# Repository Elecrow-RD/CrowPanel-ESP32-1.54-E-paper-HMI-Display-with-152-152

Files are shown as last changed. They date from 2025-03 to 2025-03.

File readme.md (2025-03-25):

### 1, Product picture

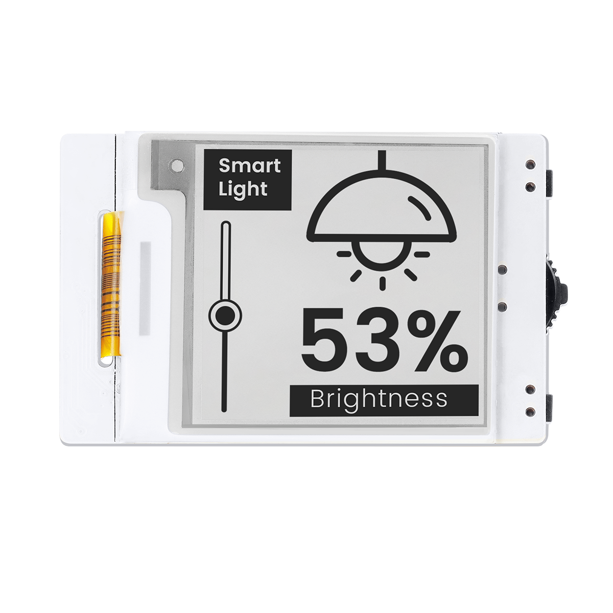
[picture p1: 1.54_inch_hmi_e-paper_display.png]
1.54_inch_hmi_e-paper_display


### 2, Product version number

| | Hardware | Software | Remark |
| ---- | --- | --- | --- |
| 1 | V1.0 | V1.0 | latest |

### 3, product information

#### Display Module Specifications

- Size: 1.54 inch
- MCU: ESP32-S3, up to 240 MHz
- Flash: 8 MB
- PSRAM: 8 MB
- Material: Active Matrix Electrophoretic Display (AM EPD)
- Driver Chip: SSD1680
- Resolution: 128(H)*296(V) Pixel
- Pixel pitch: 0.227*0.226
- Viewing Angle: Full Viewing Angle
- Communication interface: 3-/4-wire SPI
- Interface: UART0 x1, BAT x1
- Button: Dial Switch x1, Menu Button x1, Back Button x1, REST Button x1, BOOT Button x1
- Development Environment: Arduino IDE、ESP IDF、MicroPython
- Display Color: Black and white
- Refresh Mode: Partial refresh (saves more power)
- Display Operation Voltage: 2.2~3.7V
- Acrylic Case: White Acrylic Case
- Operation Temperature: -0~50℃
- Storage Temperature: -25~70℃
- Active Area: 37.18(H)\*48.32(L) (H*L)

### 4, Use the driver module

| Name | dependency library |
| --- | --- |
| SSD1680 | EPD<br />version=1.0.0 |

### 5,Quick Start

##### Arduino IDE starts

1.Download the library files used by this product to the 'libraries' folder.

C:\Users\Documents\Arduino\libraries\



2.Open the Arduino IDE

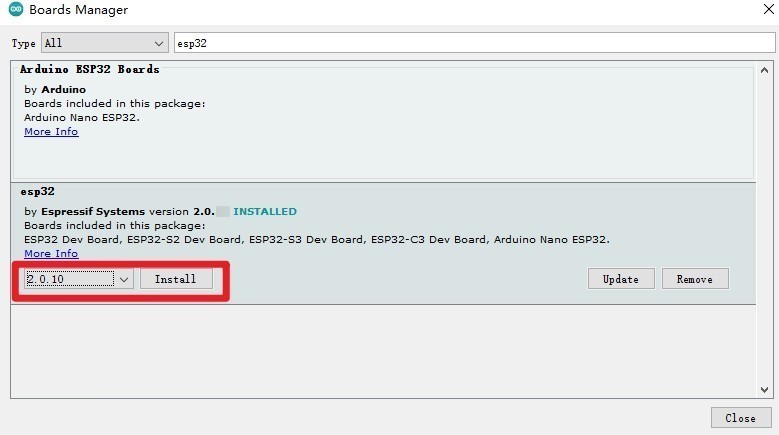
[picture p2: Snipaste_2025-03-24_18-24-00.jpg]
Snipaste_2025-03-24_18-24-00


3.Open the code configuration environment and burn it

setting

### 6,Folder structure.

|--3D file： Contains 3D model files (.stp) for the hardware. These files can be used for visualization, enclosure design, or integration into CAD software.

|--Datasheet: Includes datasheets for components used in the project, providing detailed specifications, electrical characteristics, and pin configurations.

|--Eagle_SCH&PCB: Contains **Eagle CAD** schematic (`.sch`) and PCB layout (`.brd`) files. These are used for circuit design and PCB manufacturing.

|--example: Provides example code and projects to demonstrate how to use the hardware and libraries. These examples help users get started quickly.

|--factory_firmware: Stores pre-compiled factory firmware that can be directly flashed onto the device. This ensures the device runs the default functionality.

|--factory_sourcecode: Contains the source code for the factory firmware, allowing users to modify and rebuild the firmware as needed.

### 7,Pin definition

#define SCK 12

#define MOSI 11

#define RES 10

#define DC 13

#define CS 14

#define BUSY 9

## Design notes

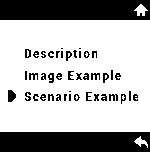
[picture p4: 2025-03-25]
factory_soucecode/1.54_tow/pic/ui_1-54_BW/UI_1-54_BW_拨轮页面-03.bmp

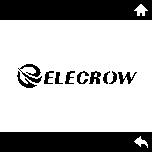
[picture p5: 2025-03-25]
factory_soucecode/1.54_tow/pic/NEW_UI_1-54_BW_/NEW_UI_1-54_BW_img-01.bmp

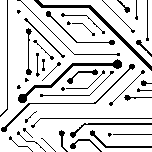
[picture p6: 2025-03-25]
factory_soucecode/1.54_tow/pic/ui_1-54_BW/UI_1-54_BW_img-07.bmp

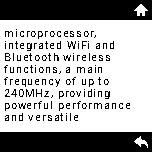
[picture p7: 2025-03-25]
factory_soucecode/1.54_tow/pic/NEW_UI_1-54_BW_202408_02/NEW_UI_1-54_BW_202408_02/NEW_UI_1-54_BW_Product-Description-02.bmp

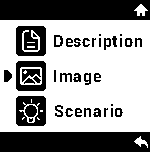
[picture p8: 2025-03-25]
factory_soucecode/1.54_tow/pic/NEW_UI_1-54_BW_/NEW_UI_1-54_BW_拨轮页面-02.bmp

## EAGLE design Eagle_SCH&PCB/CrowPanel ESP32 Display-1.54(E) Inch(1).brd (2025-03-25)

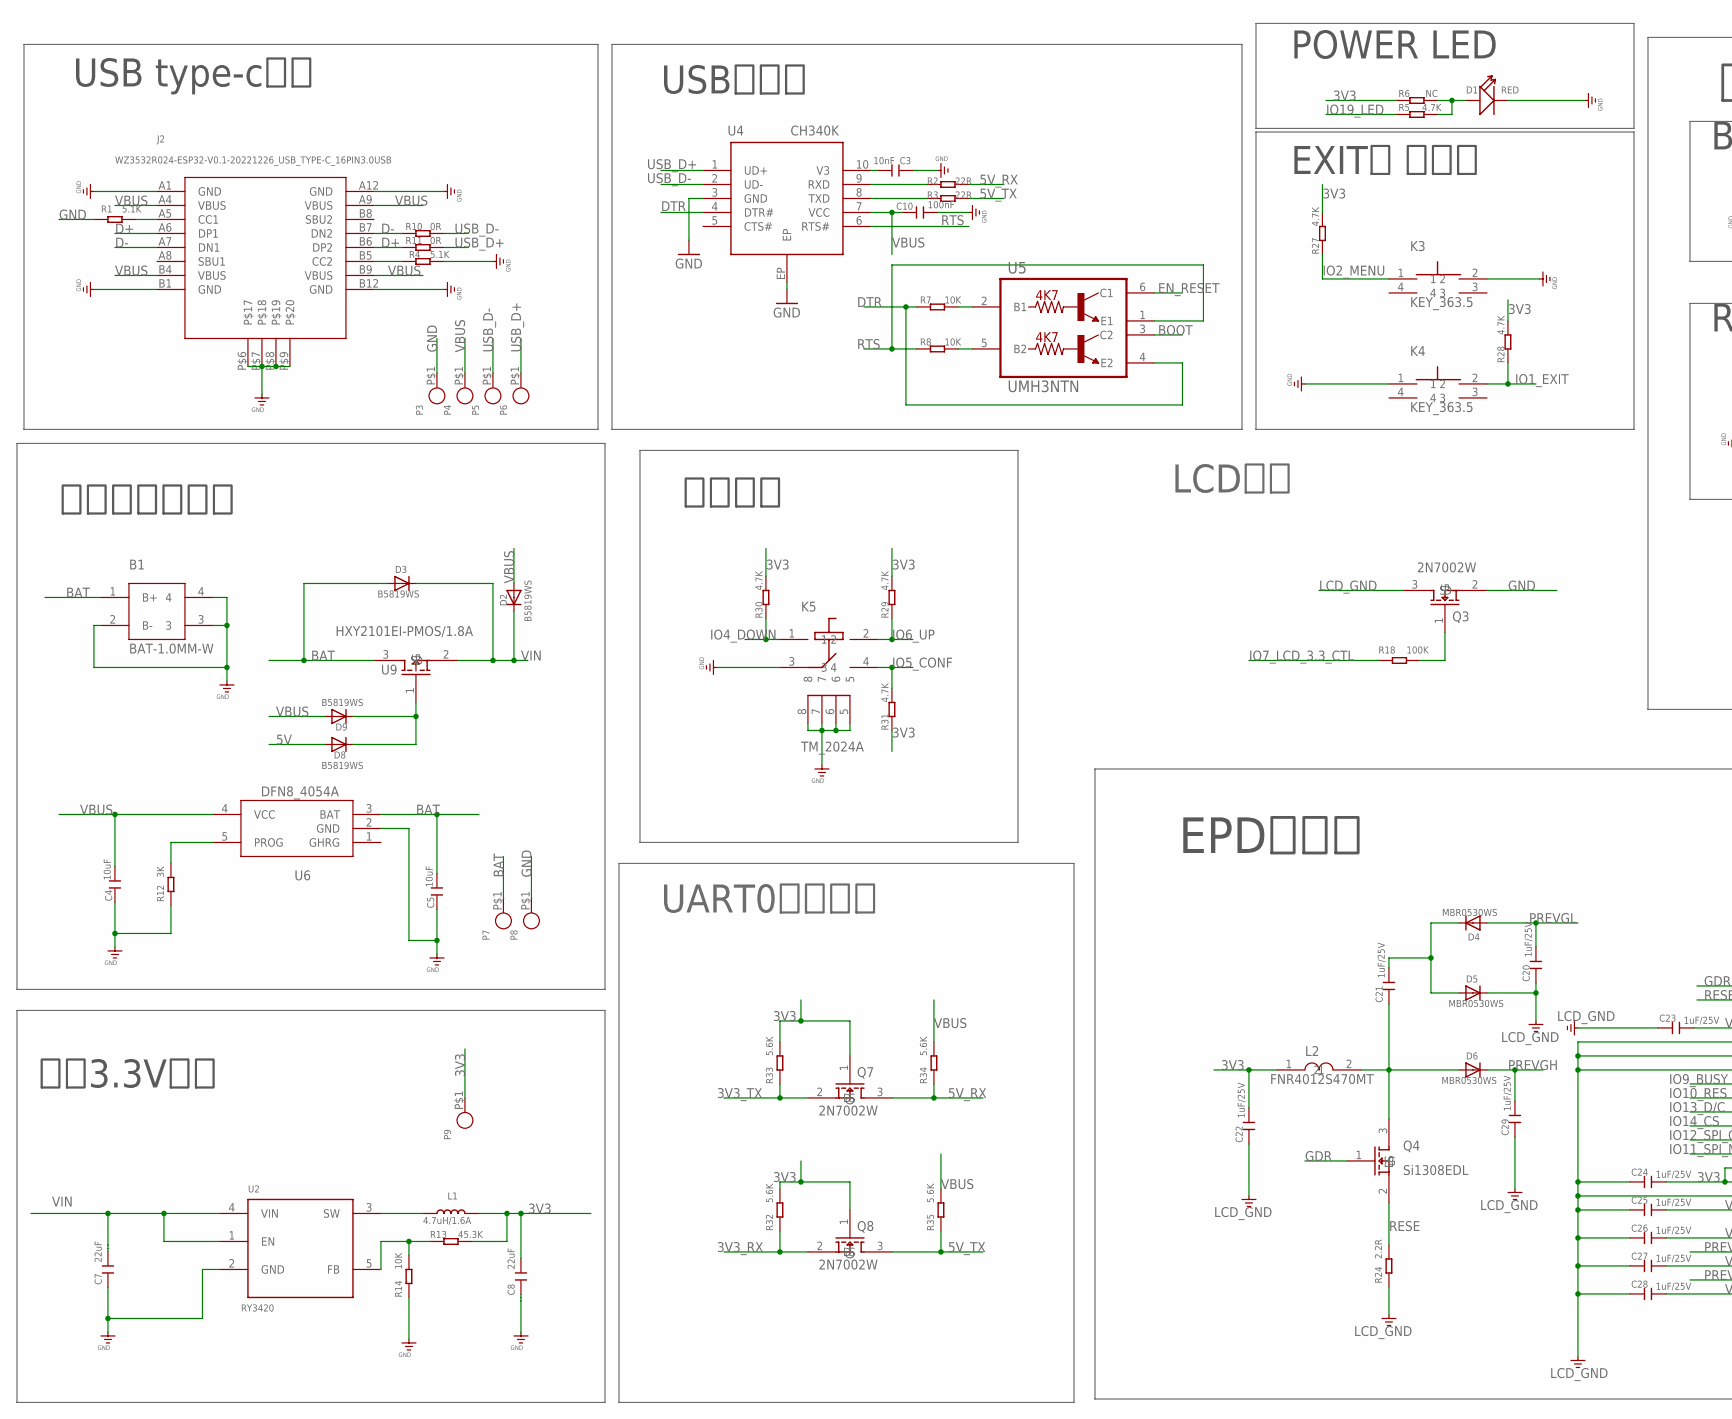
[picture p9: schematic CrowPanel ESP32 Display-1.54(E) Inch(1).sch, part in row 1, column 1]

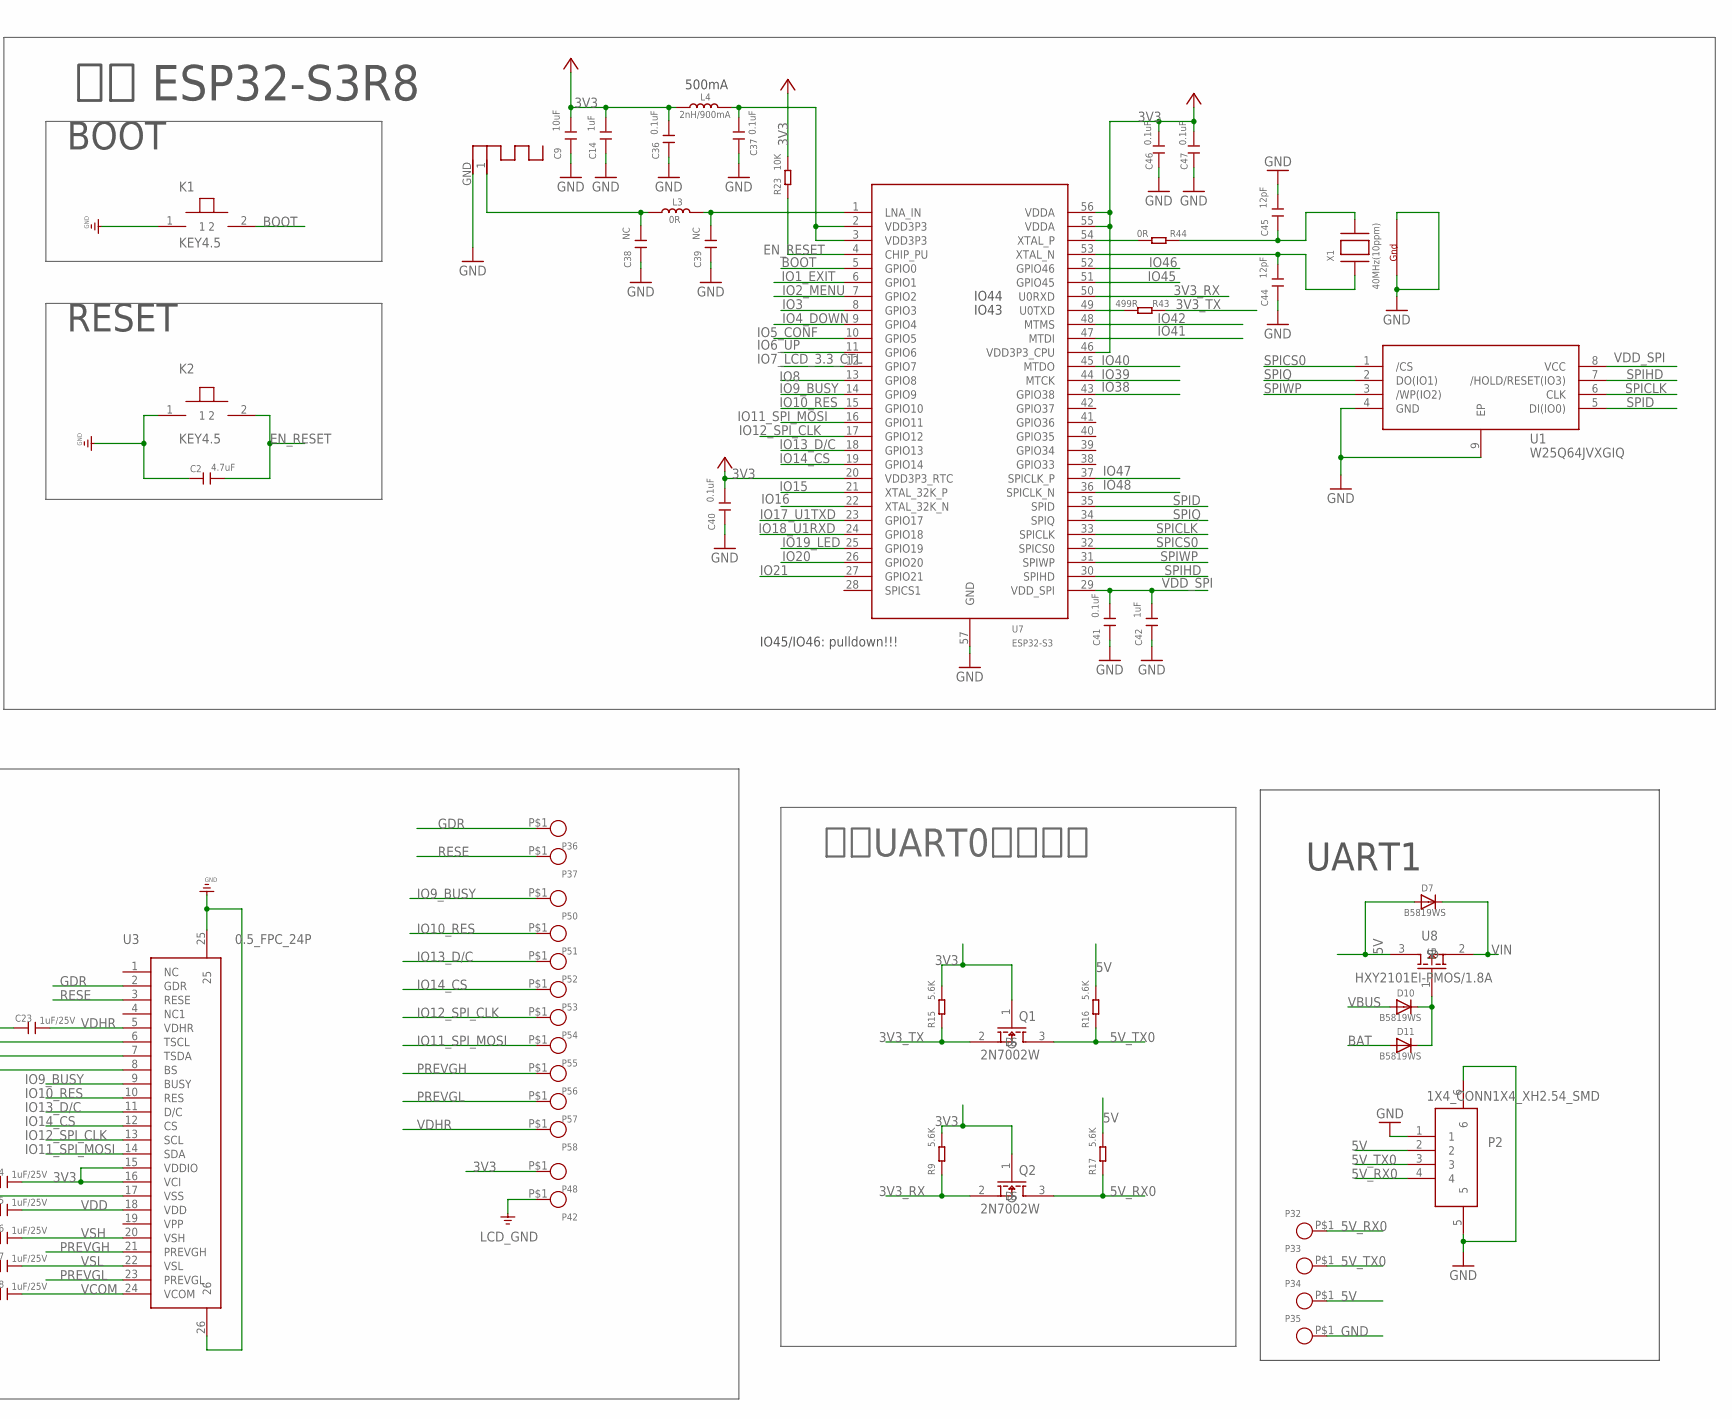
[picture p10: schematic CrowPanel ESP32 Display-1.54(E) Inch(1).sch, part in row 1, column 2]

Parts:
ANT1: ADAFRUIT_ANTENNA; ADAFRUIT_RN-ANT
B1: BAT-1.0MM-W; SH1.0MM-W
C2: 4.7uF; 0402
C3: 10nF; 0402
C4, C5, C9: 10uF; 0402
C7, C8: 22uF; 0603
C10: 100nF; 0402
C14, C42: 1uF; 0402
C20, C21, C22, C23, C24, C25, C26, C27, C28, C29: 1uF/25V; 0402
C36, C37, C40, C41, C46, C47: 0.1uF; 0402
C38, C39: NC; 0402
C44, C45: 12pF; 0402
D1: RED; A_XBJ_DISCRETE_LED-0603
D2, D3, D7, D8, D9, D10, D11: B5819WS; DISCRETE_SOD323
D4, D5, D6: MBR0530WS; DISCRETE_SOD323
J2: WZ3532R024-ESP32-V0.1-20221226_USB_TYPE-C_16PIN3.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; WZ3532R024-ESP32-V0.1-20221226_KEVIN_3.0TYPEC-SMD
K1, K2: KEY4.5; KEY-4.5
K3, K4: KEY_363.5; KEY_3*6*3.5
K5: TM_2024A
L1: 4.7uH/1.6A; A9G_DISCRETE_L0805
L2: FNR4012S470MT
L3: 0R; L0402
L4: 2nH/900mA; L0402
P2: 1X4_CONN1X4_XH2.54_SMD; CONN-SMD-4P-P2.54
P3, P4, P5, P6, P7, P8, P9, P32, P33, P34, P35, P36, P37, P42, P48, P50, P51, P52, P53, P54, P55, P56, P57, P58: CROWPI_POW_PADPAD-1.0MM; CROWPI_POW_PAD-1.0MM
Q1, Q2, Q3, Q7, Q8: 2N7002W; SOT-323_W
Q4: Si1308EDL; SOT-323_W
R1, R4: 5.1K; 0402
R2, R3: 22R; 0402
R5, R27, R28, R29, R30, R31: 4.7K; 0402
R6: NC; 0402
R7, R8, R14, R23: 10K; 0402
R9, R15, R16, R17, R32, R33, R34, R35: 5.6K; 0402
R10, R11, R44: 0R; 0402
R12: 3K; 0402
R13: 45.3K; 0402
R18: 100K; 0402
R24: 2.2R; 0402
R43: 499R; 0402
U1: W25Q64JVXGIQ; XSON-EP(4×4)
U2: RY3420; CROWBOT_-V1.0-20220525_A_XBJ_SOT23-5
U3: 0.5_FPC_24P
U4: CH340K; ESOP-10-EP-150MIL
U5: UMH3NTN; SOP65P210X100-6N
U6: DFN8_4054A; DFN8_SOP23-5
U7: ESP32-S3; QFN56-7*7MM
U8, U9: HXY2101EI-PMOS/1.8A; SOT-323_W
X1: 40MHz(10ppm); ADAFRUIT_NX3225

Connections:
3V3: C8.2, C9.2, C14.2, C22.1, C24.1, C36.2, C40.2, C46.2, C47.2, L1.2, L2.1, L4.1, P9.P$1, P48.P$1, Q1.1 (G), Q2.1 (G), Q7.1 (G), Q8.1 (G), R6.2, R9.2, R13.2, R15.2, R23.2, R27.2, R28.2, R29.2, R30.2, R31.1, R32.2, R33.2, U3.15 (VDDIO), U3.16 (VCI), U7.20 (VDD3P3_RTC), U7.46 (VDD3P3_CPU), U7.55 (VDDA), U7.56 (VDDA)
3V3_RX: Q2.2 (S), Q8.2 (S), R9.1, R32.1, U7.50 (U0RXD)
3V3_TX: Q1.2 (S), Q7.2 (S), R15.1, R33.1, R43.1
5V: D7.+ (A), D8.+ (A), P2.2, P34.P$1, R16.2, R17.2, U8.3 (D)
5V_RX: Q7.3 (D), R2.2, R34.1
5V_RX0: P2.4, P32.P$1, Q2.3 (D), R17.1
5V_TX: Q8.3 (D), R3.2, R35.1
5V_TX0: P2.3, P33.P$1, Q1.3 (D), R16.1
BAT: B1.1 (B+), C5.2, D3.+ (A), D11.+ (A), P7.P$1, U6.3 (BAT), U9.3 (D)
BOOT: K1.2, U5.3 (C2), U7.5 (GPIO0)
D+: J2.A6 (DP1), J2.B6 (DP2), R11.1
D-: J2.A7 (DN1), J2.B7 (DN2), R10.1
DTR: R7.1, U4.4 (DTR#), U5.4 (E2)
EN_RESET: C2.2, K2.2, R23.1, U5.6 (C1), U7.4 (CHIP_PU)
GDR: P36.P$1, Q4.1 (G), U3.2 (GDR)
GND: ANT1.GND, B1.2 (B-), B1.3, B1.4, C2.1, C3.1, C4.1, C5.1, C7.1, C8.1, C9.1, C10.2, C14.1, C36.1, C37.1, C38.1, C39.1, C40.1, C41.1, C42.1, C44.1, C45.2, C46.1, C47.1, D1.-, J2.A1 (GND), J2.A12 (GND), J2.B1 (GND), J2.B12 (GND), J2.P$6, J2.P$7, J2.P$8, J2.P$9, K1.1, K2.1, K3.2, K4.1, K5.3, K5.5, K5.6, K5.7, K5.8, P2.1, P2.5, P2.6, P3.P$1, P8.P$1, P35.P$1, Q3.2 (S), R1.1, R4.2, R12.1, R14.1, U1.4 (GND), U1.9 (EP), U2.2 (GND), U3.25, U3.26, U4.3 (GND), U4.EP, U6.2 (GND), U7.57 (GND), X1.2 (G2), X1.4 (G1)
IO1_EXIT: K4.2, R28.1, U7.6 (GPIO1)
IO2_MENU: K3.1, R27.1, U7.7 (GPIO2)
IO3: U7.8 (GPIO3)
IO4_DOWN: K5.1, R30.1, U7.9 (GPIO4)
IO5_CONF: K5.4, R31.2, U7.10 (GPIO5)
IO6_UP: K5.2, R29.1, U7.11 (GPIO6)
IO7_LCD_3.3_CTL: R18.1, U7.12 (GPIO7)
IO8: U7.13 (GPIO8)
IO9_BUSY: P50.P$1, U3.9 (BUSY), U7.14 (GPIO9)
IO10_RES: P51.P$1, U3.10 (RES), U7.15 (GPIO10)
IO11_SPI_MOSI: P55.P$1, U3.14 (SDA), U7.16 (GPIO11)
IO12_SPI_CLK: P54.P$1, U3.13 (SCL), U7.17 (GPIO12)
IO13_D/C: P52.P$1, U3.11 (D/C), U7.18 (GPIO13)
IO14_CS: P53.P$1, U3.12 (CS), U7.19 (GPIO14)
IO15: U7.21 (XTAL_32K_P)
IO16: U7.22 (XTAL_32K_N)
IO17_U1TXD: U7.23 (GPIO17)
IO18_U1RXD: U7.24 (GPIO18)
IO19_LED: R5.2, U7.25 (GPIO19)
IO20: U7.26 (GPIO20)
IO21: U7.27 (GPIO21)
IO38: U7.43 (GPIO38)
IO39: U7.44 (MTCK)
IO40: U7.45 (MTDO)
IO41: U7.47 (MTDI)
IO42: U7.48 (MTMS)
IO45: U7.51 (GPIO45)
IO46: U7.52 (GPIO46)
IO47: U7.37 (SPICLK_P)
IO48: U7.36 (SPICLK_N)
LCD_GND: C20.2, C22.2, C23.2, C24.2, C25.2, C26.2, C27.2, C28.2, C29.2, D5.- (C), P42.P$1, Q3.3 (D), R24.1, U3.6 (TSCL), U3.7 (TSDA), U3.8 (BS), U3.17 (VSS)
unnamed: R7.2, U5.2 (B1)
unnamed: D10.- (C), D11.- (C), U8.1 (G)
unnamed: R8.2, U5.5 (B2)
unnamed: J2.A5 (CC1), R1.2
unnamed: D8.- (C), D9.- (C), U9.1 (G)
unnamed: Q3.1 (G), R18.2
unnamed: R3.1, U4.8 (TXD)
unnamed: R13.1, R14.2, U2.5 (FB)
unnamed: C3.2, U4.10 (V3)
unnamed: L1.1, U2.3 (SW)
unnamed: J2.B5 (CC2), R4.1
unnamed: R12.2, U6.5 (PROG)
unnamed: D1.+, R5.1, R6.1
unnamed: ANT1.1 (FEED), C38.2, L3.1
unnamed: C39.2, L3.2, U7.1 (LNA_IN)
unnamed: C37.2, L4.2, U7.2 (VDD3P3), U7.3 (VDD3P3)
unnamed: R2.1, U4.9 (RXD)
unnamed: R44.2, U7.54 (XTAL_P)
unnamed: C21.1, D4.- (C), D5.+ (A)
unnamed: C21.2, D6.+ (A), L2.2, Q4.3 (D)
unnamed: R43.2, U7.49 (U0TXD)
unnamed: C44.2, U7.53 (XTAL_N), X1.1 (X1)
unnamed: C45.1, R44.1, X1.3 (X2)
PREVGH: C29.1, D6.- (C), P56.P$1, U3.21 (PREVGH)
PREVGL: C20.1, D4.+ (A), P57.P$1, U3.23 (PREVGL)
RESE: P37.P$1, Q4.2 (S), R24.2, U3.3 (RESE)
RTS: R8.1, U4.6 (RTS#), U5.1 (E1)
SPICLK: U1.6 (CLK), U7.33 (SPICLK)
SPICS0: U1.1 (/CS), U7.32 (SPICS0)
SPID: U1.5 (DI(IO0)), U7.35 (SPID)
SPIHD: U1.7 (/HOLD/RESET(IO3)), U7.30 (SPIHD)
SPIQ: U1.2 (DO(IO1)), U7.34 (SPIQ)
SPIWP: U1.3 (/WP(IO2)), U7.31 (SPIWP)
USB_D+: P6.P$1, R11.2, U4.1 (UD+)
USB_D-: P5.P$1, R10.2, U4.2 (UD-)
VBUS: C4.2, C10.1, D2.+ (A), D9.+ (A), D10.+ (A), J2.A4 (VBUS), J2.A9 (VBUS), J2.B4 (VBUS), J2.B9 (VBUS), P4.P$1, R34.2, R35.2, U4.7 (VCC), U6.4 (VCC)
VCOM: C28.1, U3.24 (VCOM)
VDD: C25.1, U3.18 (VDD)
VDD_SPI: C41.2, C42.2, U1.8 (VCC), U7.29 (VDD_SPI)
VDHR: C23.1, P58.P$1, U3.5 (VDHR)
VIN: C7.2, D2.- (C), D3.- (C), D7.- (C), U2.1 (EN), U2.4 (VIN), U8.2 (S), U9.2 (S)
VSH: C26.1, U3.20 (VSH)
VSL: C27.1, U3.22 (VSL)

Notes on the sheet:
USB type-c座子
USB转串口
EXIT键 主页键
主控 ESP32-S3R8
EPD屏接口
拨轮开关
系统3.3V电源
电池及控制电路
BOOT
RESET
UART0电平转换
LCD使能
500mA
IO45/IO46: pulldown!!!
IO43
IO44
UART1
POWER LED
外接UART0电平转换

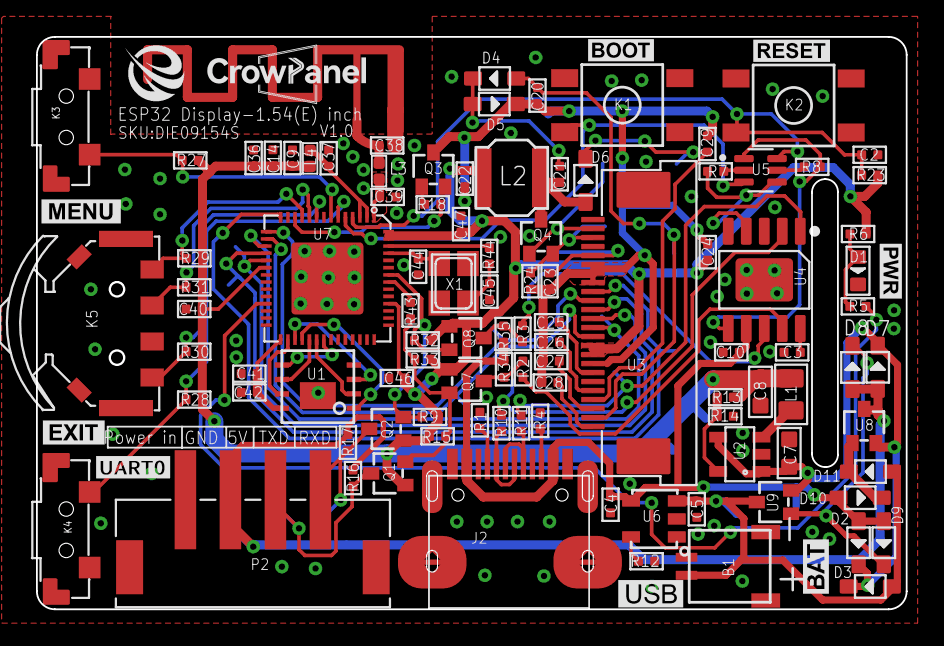
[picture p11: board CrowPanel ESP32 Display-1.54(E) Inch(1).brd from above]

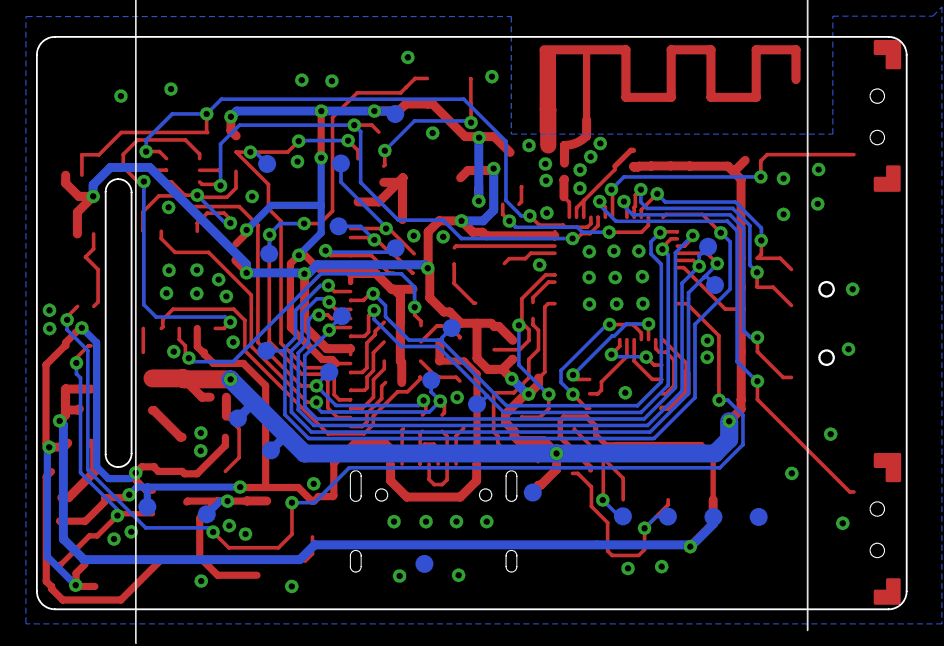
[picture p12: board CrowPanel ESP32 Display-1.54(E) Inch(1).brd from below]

Board: 2 copper layers, 48.3 x 31.8 mm, 126 parts (24 on the bottom side), 73 nets.

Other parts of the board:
U$6: LOGO-MIN

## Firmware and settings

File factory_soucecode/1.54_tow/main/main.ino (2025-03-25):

#include "EPD_GUI.h"
#include "Pic.h"
#include "Pic_boot_screen.h"
#include "pic_menu.h"
#include "pic_home.h"
#include "pic_description.h"
#include "pic_image.h"
#include "pic_scenario.h"


#include <WiFi.h>
#include <esp_wifi.h>

#include "BLEDevice.h"              //BLE驱动库
#include "BLEServer.h"              //BLE蓝牙服务器库
#include "BLEUtils.h"               //BLE实用程序库
#include "BLE2902.h"                //特征添加描述符库
BLECharacteristic *pCharacteristic;
BLEServer *pServer;
BLEService *pService;
bool deviceConnected = false;
char BLEbuf[32] = {0};
uint32_t cnt = 0;

#define SERVICE_UUID           "6E400001-B5A3-F393-E0A9-E50E24DCCA9E" // UART service UUID
#define CHARACTERISTIC_UUID_RX "6E400002-B5A3-F393-E0A9-E50E24DCCA9E"
#define CHARACTERISTIC_UUID_TX "6E400003-B5A3-F393-E0A9-E50E24DCCA9E"

class MyServerCallbacks: public BLEServerCallbacks {
    void onConnect(BLEServer* pServer) {
      deviceConnected = true;
      Serial.println("------> BLE connect .");
    };

    void onDisconnect(BLEServer* pServer) {
      deviceConnected = false;
      Serial.println("------> BLE disconnect .");
      pServer->startAdvertising(); // restart advertising
      Serial.println("start advertising");
    }
};

class MyCallbacks: public BLECharacteristicCallbacks {
    void onWrite(BLECharacteristic *pCharacteristic) {
      String rxValue = pCharacteristic->getValue();

      if (rxValue.length() > 0) {
        Serial.print("------>Received Value: ");

        for (int i = 0; i < rxValue.length(); i++) {
          Serial.print(rxValue[i]);
        }
        Serial.println();

        if (rxValue.indexOf("A") != -1) {
          Serial.print("Rx A!");
        }
        else if (rxValue.indexOf("B") != -1) {
          Serial.print("Rx B!");
        }
        Serial.println();
      }
    }
};

//打印唤醒原因
void print_wakeup_reason() {
  esp_sleep_wakeup_cause_t wakeup_reason;

  wakeup_reason = esp_sleep_get_wakeup_cause();

  switch (wakeup_reason)
  {
    case ESP_SLEEP_WAKEUP_EXT0 : Serial.println("Wakeup caused by external signal using RTC_IO"); break;
    case ESP_SLEEP_WAKEUP_EXT1 : Serial.println("Wakeup caused by external signal using RTC_CNTL"); break;
    case ESP_SLEEP_WAKEUP_TIMER : Serial.println("Wakeup caused by timer"); break;
    case ESP_SLEEP_WAKEUP_TOUCHPAD : Serial.println("Wakeup caused by touchpad"); break;
    case ESP_SLEEP_WAKEUP_ULP : Serial.println("Wakeup caused by ULP program"); break;
    default : Serial.printf("Wakeup was not caused by deep sleep: %d\n", wakeup_reason); break;
  }
}

uint8_t ImageBW[2888];

//主页键
#define HOME_KEY 2
//退出键
#define EXIT_KEY 1

//轮播开关
//上一页
#define PRV_KEY 6
//下一页
#define NEXT_KEY 4
//确认
#define OK_KEY 5

int8_t prv_menu_pos;
uint8_t peg_pos;  //页游标
int8_t slide_pos; //界面游标
int8_t three_interface_flag; //三级界面标志
int8_t scenario_ctl;  //开关标志
int8_t scenario_ctl1;
int8_t scenario_ctl2;
int8_t scenario_ctl3;
int8_t scenario_ctl4;
int sleep_num; //进去睡眠计数
bool test_flag = false;
char val;
uint8_t KEY_NUM;
uint8_t KEY_SCAN()
{
  if (test_flag != false)
  {
    return 0;
  }

  KEY_NUM = 0;
  if (digitalRead(HOME_KEY) == 0)
  {
    delay(25);
    int i = 0;
    if (digitalRead(HOME_KEY) == 0)
    {
      Serial.println("HOME_KEY");
      sleep_num = 0;
      Serial.println("sleep now clear");
      while (digitalRead(HOME_KEY) == 0)  //长按5s清屏
      {
        i++;
        Serial.print("HOME_KEY KEEP ");
        Serial.println(i);
        delay(10);
        if (i == 500)
        {
          Serial.println("Display_Clear ....... ");
          clear_all();
//          return 0;
          while(1);
        }
      }
      KEY_NUM = 1;
    }
  }
  else if (digitalRead(EXIT_KEY) == 0)
  {
    delay(25);
    if (digitalRead(EXIT_KEY) == 0)
    {
      Serial.println("EXIT_KEY");
      KEY_NUM = 2;
    }
  }
  else if (digitalRead(PRV_KEY) == 0)
  {
    delay(25);
    if (digitalRead(PRV_KEY) == 0)
    {
      Serial.println("PRV_KEY");
      KEY_NUM = 3;
    }
  }
  else if (digitalRead(NEXT_KEY) == 0)
  {
    delay(25);
    if (digitalRead(NEXT_KEY) == 0)
    {
      Serial.println("NEXT_KEY");
      KEY_NUM = 4;
    }
  }
  else if (digitalRead(OK_KEY) == 0)
  {
    delay(25);
    if (digitalRead(OK_KEY) == 0)
    {
      Serial.println("OK_KEY");
      KEY_NUM = 5;
    }
  }

  return KEY_NUM;
}

void clear_all()
{
  EPD_Init();
  EPD_Display_Clear();
  EPD_Update();
  EPD_DeepSleep();
}

void show_home_menu()
{
  EPD_HW_RESET();
  EPD_ShowPicture(0, 0, 152, 152, gImage_menu, BLACK);
  EPD_Display(ImageBW);
  EPD_FastUpdate();
  EPD_DeepSleep();

  peg_pos = 1;
  slide_pos = 0;
  prv_menu_pos = 0;
}

void show_home_menu1()
{
  EPD_HW_RESET();
  EPD_ShowPicture(0, 0, 152, 152, gImage_menu1, BLACK);
  EPD_Display(ImageBW);
  EPD_FastUpdate();
  EPD_DeepSleep();

  peg_pos = 1;
  slide_pos = 1;
  prv_menu_pos = 1;
}

void show_home_menu2()
{
  EPD_HW_RESET();
  EPD_ShowPicture(0, 0, 152, 152, gImage_menu2, BLACK);
  EPD_Display(ImageBW);
  EPD_FastUpdate();
  EPD_DeepSleep();

  peg_pos = 1;
  slide_pos = 2;
  prv_menu_pos = 2;
}

void show_home_menu_pos(int8_t show_pos)
{
  switch (show_pos)
  {
    case 0:

      show_home_menu();

      peg_pos = 1;
      slide_pos = 0;
      prv_menu_pos = 0;
      break;
    case 1:

      show_home_menu1();

      peg_pos = 1;
      slide_pos = 1;
      prv_menu_pos = 1;
      break;
    case 2:

      show_home_menu2();

      peg_pos = 1;
      slide_pos = 2;
      prv_menu_pos = 2;
      break;
    default:
      break;
  }
}

void show_description(int show_pos)
{
  if (show_pos == 0)
  {
    slide_pos = 0;
  }
  switch (show_pos)
  {
    case 0:
      //第一页介绍
      EPD_HW_RESET();
      EPD_ShowPicture(0, 0, 152, 152, gImage_description, BLACK);
      EPD_Display(ImageBW);
      EPD_FastUpdate();
      EPD_DeepSleep();

      peg_pos = 2;
      slide_pos = 0;
      prv_menu_pos = 0;
      three_interface_flag = 0;
      test_flag = false;

      break;
    case 1:
      EPD_HW_RESET();
      EPD_ShowPicture(0, 0, 152, 152, gImage_description1, BLACK);
      EPD_Display(ImageBW);
      EPD_FastUpdate();
      EPD_DeepSleep();

      peg_pos = 2;
      slide_pos = 1;
      prv_menu_pos = 0;
      three_interface_flag = 0;
      test_flag = false;

      break;
    case 2:
      EPD_HW_RESET();
      EPD_ShowPicture(0, 0, 152, 152, gImage_description2, BLACK);
      EPD_Display(ImageBW);
      EPD_FastUpdate();
      EPD_DeepSleep();

      peg_pos = 2;
      slide_pos = 2;
      prv_menu_pos = 0;
      three_interface_flag = 0;
      test_flag = false;

      break;
    case 3:
      EPD_HW_RESET();
      EPD_ShowPicture(0, 0, 152, 152, gImage_description3, BLACK);
      EPD_Display(ImageBW);
      EPD_FastUpdate();
      EPD_DeepSleep();

      peg_pos = 2;
      slide_pos = 3;
      prv_menu_pos = 0;
      three_interface_flag = 0;
      test_flag = false;

      break;
    case 4:
      EPD_HW_RESET();
      EPD_ShowPicture(0, 0, 152, 152, gImage_description4, BLACK);
      EPD_Display(ImageBW);
      EPD_FastUpdate();
      EPD_DeepSleep();

      peg_pos = 2;
      slide_pos = 4;
      prv_menu_pos = 0;
      three_interface_flag = 0;
      test_flag = false;

      break;
    case 5:
      EPD_HW_RESET();
      EPD_ShowPicture(0, 0, 152, 152, gImage_description5, BLACK);
      EPD_Display(ImageBW);
      EPD_FastUpdate();
      EPD_DeepSleep();

      peg_pos = 2;
      slide_pos = 5;
      prv_menu_pos = 0;
      three_interface_flag = 0;
      test_flag = false;

      break;
    case 6:
      EPD_HW_RESET();
      EPD_ShowPicture(0, 0, 152, 152, gImage_description6, BLACK);
      EPD_Display(ImageBW);
      EPD_FastUpdate();
      EPD_DeepSleep();

      peg_pos = 2;
      slide_pos = 6;
      prv_menu_pos = 0;
      three_interface_flag = 0;
      test_flag = false;

      break;
    default:
      break;
  }
}

void show_image_example(int show_pos)
{
  if (show_pos == 0)
  {
    slide_pos = 0;
  }
  switch (show_pos)
  {
    case 0:
      EPD_HW_RESET();
      EPD_ShowPicture(0, 0, 152, 152, gImage_image, BLACK);
      EPD_Display(ImageBW);
      EPD_FastUpdate();
      EPD_DeepSleep();

      peg_pos = 2;
      prv_menu_pos = 1;
      slide_pos = 0;
      three_interface_flag = 1;
      test_flag = false;
      break;
    case 1:
      EPD_HW_RESET();
      EPD_ShowPicture(0, 0, 152, 152, gImage_image1, BLACK);
      EPD_Display(ImageBW);
      EPD_FastUpdate();
      EPD_DeepSleep();

      peg_pos = 2;
      prv_menu_pos = 1;
      slide_pos = 1;
      three_interface_flag = 1;
      test_flag = false;
      break;
    case 2:
      EPD_HW_RESET();
      EPD_ShowPicture(0, 0, 152, 152, gImage_image2, BLACK);
      EPD_Display(ImageBW);
      EPD_FastUpdate();
      EPD_DeepSleep();

      peg_pos = 2;
      prv_menu_pos = 1;
      slide_pos = 2;
      three_interface_flag = 1;
      test_flag = false;
      break;
    case 3:
      EPD_HW_RESET();
      EPD_ShowPicture(0, 0, 152, 152, gImage_image3, BLACK);
      EPD_Display(ImageBW);
      EPD_FastUpdate();
      EPD_DeepSleep();

      peg_pos = 2;
      prv_menu_pos = 1;
      slide_pos = 3;
      three_interface_flag = 1;
      test_flag = false;
      break;
    case 4:
      EPD_HW_RESET();
      EPD_ShowPicture(0, 0, 152, 152, gImage_image4, BLACK);
      EPD_Display(ImageBW);
      EPD_FastUpdate();
      EPD_DeepSleep();

      peg_pos = 2;
      prv_menu_pos = 1;
      slide_pos = 4;
      three_interface_flag = 1;
      test_flag = false;
      break;
    case 5:
      EPD_HW_RESET();
      EPD_ShowPicture(0, 0, 152, 152, gImage_image5, BLACK);
      EPD_Display(ImageBW);
      EPD_FastUpdate();
      EPD_DeepSleep();

      peg_pos = 2;
      prv_menu_pos = 1;
      slide_pos = 5;
      three_interface_flag = 1;
      test_flag = false;
      break;
    case 6:
      EPD_HW_RESET();
      EPD_ShowPicture(0, 0, 152, 152, gImage_image6, BLACK);
      EPD_Display(ImageBW);
      EPD_FastUpdate();
      EPD_DeepSleep();

      peg_pos = 2;
      prv_menu_pos = 1;
      slide_pos = 6;
      three_interface_flag = 1;
      test_flag = false;
      break;
    default:
      break;
  }
}

void show_scenario_example_pos(int show_pos)  //scenario 显示游标  坐标左右颠倒
{
  if (show_pos == 0)
  {
    slide_pos = 0;
  }
  switch (show_pos)
  {
    case 0:
      EPD_HW_RESET();
      EPD_ShowPicture(30, 138, 90, 8, gImage_scenario_pos, BLACK);
      EPD_Display(ImageBW);
      EPD_FastUpdate();
      EPD_DeepSleep();


      slide_pos = 0;
      peg_pos = 2;
      prv_menu_pos = 2;
      three_interface_flag = 2;
      test_flag = false;
      break;
    case 1:
      EPD_HW_RESET();
      EPD_ShowPicture(30, 138, 90, 8, gImage_scenario_pos1, BLACK);
      EPD_Display(ImageBW);
      EPD_FastUpdate();
      EPD_DeepSleep();

      slide_pos = 1;
      peg_pos = 2;
      prv_menu_pos = 2;
      three_interface_flag = 2;
      test_flag = false;
      break;
    case 2:
      EPD_HW_RESET();
      EPD_ShowPicture(30, 138, 90, 8, gImage_scenario_pos2, BLACK);
      EPD_Display(ImageBW);
      EPD_FastUpdate();
      EPD_DeepSleep();

      slide_pos = 2;
      peg_pos = 2;
      prv_menu_pos = 2;
      three_interface_flag = 2;
      test_flag = false;
      break;
    case 3:
      EPD_HW_RESET();
      EPD_ShowPicture(30, 138, 90, 8, gImage_scenario_pos3, BLACK);
      EPD_Display(ImageBW);
      EPD_FastUpdate();
      EPD_DeepSleep();

      slide_pos = 3;
      peg_pos = 2;
      prv_menu_pos = 2;
      three_interface_flag = 2;
      test_flag = false;
      break;
    case 4:
      EPD_HW_RESET();
      EPD_ShowPicture(30, 138, 90, 8, gImage_scenario_pos4, BLACK);
      EPD_Display(ImageBW);
      EPD_FastUpdate();
      EPD_DeepSleep();

      slide_pos = 4;
      prv_menu_pos = 2;
      peg_pos = 2;
      three_interface_flag = 2;
      test_flag = false;
      break;
    default:
      break;
  }
}

void show_scenario_example_ctl(int show_pos) //scenario 显示开关
{
  if (show_pos == 0)
  {
    slide_pos = 0;
  }

  switch (show_pos)
  {
    case 0:
      if (scenario_ctl == 0)
      {
        EPD_HW_RESET();
        EPD_ShowPicture(30, 6, 14, 56, gImage_scenario_ctl_on, BLACK);
        EPD_Display(ImageBW);
        EPD_FastUpdate();
        EPD_DeepSleep();

        scenario_ctl = 1;
      }
      else if (scenario_ctl == 1)
      {

        EPD_HW_RESET();
        EPD_ShowPicture(30, 6, 14, 56, gImage_scenario_ctl_off, BLACK);
        EPD_Display(ImageBW);
        EPD_FastUpdate();
        EPD_DeepSleep();


        scenario_ctl = 0;
      }
      break;
    case 1:
      if (scenario_ctl1 == 0)
      {
        EPD_HW_RESET();
        EPD_ShowPicture(49, 6, 14, 56, gImage_scenario_ctl_on, BLACK);
        EPD_Display(ImageBW);
        EPD_FastUpdate();
        EPD_DeepSleep();

        scenario_ctl1 = 1;
      }
      else if (scenario_ctl1 == 1)
      {
        EPD_HW_RESET();
        EPD_ShowPicture(49, 6, 14, 56, gImage_scenario_ctl_off, BLACK);
        EPD_Display(ImageBW);
        EPD_FastUpdate();
        EPD_DeepSleep();

        scenario_ctl1 = 0;
      }
      break;
    case 2:
      if (scenario_ctl2 == 0)
      {
        EPD_HW_RESET();
        EPD_ShowPicture(68, 6, 14, 56, gImage_scenario_ctl_on, BLACK);
        EPD_Display(ImageBW);
        EPD_FastUpdate();
        EPD_DeepSleep();

        scenario_ctl2 = 1;
      }
      else if (scenario_ctl2 == 1)
      {
        EPD_HW_RESET();
        EPD_ShowPicture(68, 6, 14, 56, gImage_scenario_ctl_off, BLACK);
        EPD_Display(ImageBW);
        EPD_FastUpdate();
        EPD_DeepSleep();

        scenario_ctl2 = 0;
      }
      break;
    case 3:
      if (scenario_ctl3 == 0)
      {
        EPD_HW_RESET();
        EPD_ShowPicture(87, 6, 14, 56, gImage_scenario_ctl_on, BLACK);
        EPD_Display(ImageBW);
        EPD_FastUpdate();
        EPD_DeepSleep();

        scenario_ctl3 = 1;
      }
      else if (scenario_ctl3 == 1)
      {
        EPD_HW_RESET();
        EPD_ShowPicture(87, 6, 14, 56, gImage_scenario_ctl_off, BLACK);
        EPD_Display(ImageBW);
        EPD_FastUpdate();
        EPD_DeepSleep();

        scenario_ctl3 = 0;
      }
      break;
    case 4:
      if (scenario_ctl4 == 0)
      {
        EPD_HW_RESET();
        EPD_ShowPicture(106, 6, 14, 56, gImage_scenario_ctl_on, BLACK);
        EPD_Display(ImageBW);
        EPD_FastUpdate();
        EPD_DeepSleep();

        scenario_ctl4 = 1;
      }
      else if (scenario_ctl4 == 1)
      {
        EPD_HW_RESET();
        EPD_ShowPicture(106, 6, 14, 56, gImage_scenario_ctl_off, BLACK);
        EPD_Display(ImageBW);
        EPD_FastUpdate();
        EPD_DeepSleep();

        scenario_ctl4 = 0;
      }
      break;
    default:
      break;
  }
}
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
void loop()
{
  //测试串口检测
  test_task();
  if (KEY_SCAN() != 0 && test_flag == false)
  {
    sleep_num = 0;
    Serial.println("sleep now clear");
    //    Serial.println(KEY_NUM);
    switch (KEY_NUM)
    {
      case 1:
        //返回主页
        peg_pos = 1; //进入2级界面，功能页选择
        slide_pos = 0;
        prv_menu_pos = 0;
        three_interface_flag = 0;
        show_home_menu();
        scenario_ctl = 0;
        scenario_ctl1 = 0;
        scenario_ctl2 = 0;
        scenario_ctl3 = 0;
        scenario_ctl4 = 0;
        break;
      case 2:
        if (peg_pos == 1 || peg_pos == 2)
        {
          //返回
          peg_pos = 1; //进入2级界面，功能页选择

          if (prv_menu_pos == 0)
          {
            slide_pos = 0;
            prv_menu_pos = 0;
            three_interface_flag = 0;
            scenario_ctl = 0;
            scenario_ctl1 = 0;
            scenario_ctl2 = 0;
            scenario_ctl3 = 0;
            scenario_ctl4 = 0;
            show_home_menu();
          }
          else if (prv_menu_pos == 1)
          {
            slide_pos = 1;
            prv_menu_pos = 1;
            three_interface_flag = 0;
            scenario_ctl = 0;
            scenario_ctl1 = 0;
            scenario_ctl2 = 0;
            scenario_ctl3 = 0;
            scenario_ctl4 = 0;
            show_home_menu1();
          }
          else if (prv_menu_pos == 2)
          {
            slide_pos = 2;
            prv_menu_pos = 2;
            three_interface_flag = 0;
            scenario_ctl = 0;
            scenario_ctl1 = 0;
            scenario_ctl2 = 0;
            scenario_ctl3 = 0;
            scenario_ctl4 = 0;
            show_home_menu2();
          }
        }
        break;
      case 3:
        if (--slide_pos < 0)
        {
          slide_pos = 0;
          return ;
        }

        Serial.print("slide_pos : ");
        Serial.println(slide_pos);
        //2级界面上滑
        if (peg_pos == 1)
        {
          show_home_menu_pos(slide_pos);
        }
        //在3级界面上滑
        else if (peg_pos == 2)
        {
          if (three_interface_flag == 0)
          {
            show_description(slide_pos);
          }
          else if (three_interface_flag == 1)
          {
            show_image_example(slide_pos);
          }
          else if (three_interface_flag == 2)
          {
            show_scenario_example_pos(slide_pos);
          }
        }
        break;
      case 4:
        //2级界面下滑
        if (peg_pos == 1)
        {
          if (++slide_pos > 2)
          {
            slide_pos = 2;
            return ;
          }
          Serial.print("slide_pos : ");
          Serial.println(slide_pos);
          show_home_menu_pos(slide_pos);
        }
        //3级界面下滑
        else if (peg_pos == 2)
        {
          if (three_interface_flag == 0)
          {
            if (++slide_pos > 6)
            {
              slide_pos = 6;
              return ;
            }
            Serial.print("slide_pos : ");
            Serial.println(slide_pos);
            show_description(slide_pos);
          }
          else if (three_interface_flag == 1)
          {
            if (++slide_pos > 6)
            {
              slide_pos = 6;
              return ;
            }

            Serial.print("slide_pos : ");
            Serial.println(slide_pos);
            show_image_example(slide_pos);
          }
          else if (three_interface_flag == 2)
          {
            if (++slide_pos > 4)
            {
              slide_pos = 4;
              return ;
            }
            Serial.print("slide_pos : ");
            Serial.println(slide_pos);
            show_scenario_example_pos(slide_pos);
          }
        }
        break;
      case 5:
        //确定
        //2级界面确认
        if (peg_pos == 1)
        {
          Serial.println("ture into 2");
          if (slide_pos == 0)
          {
            Serial.println("into show description");
            show_description(0);
            prv_menu_pos = 0;
            peg_pos = 2;
            three_interface_flag = 0;
          }
          else if (slide_pos == 1)
          {
            Serial.println("into show image example");
            show_image_example(0);
            prv_menu_pos = 1;
            peg_pos = 2;
            three_interface_flag = 1;
          }
          else if (slide_pos == 2)
          {
            Serial.println("into show scenario example");
            peg_pos = 2;
            three_interface_flag = 2;

            EPD_HW_RESET();
            EPD_ShowPicture(0, 0, 152, 152, gImage_scenario_home, BLACK);
            EPD_Display(ImageBW);
            EPD_FastUpdate();
            EPD_DeepSleep();

            slide_pos = 0;
            prv_menu_pos = 2;
          }
        }
        //3级界面确认
        else if (peg_pos == 2)
        {
          Serial.println("ture into 3");
          if (three_interface_flag == 2) //在灯光控制界面
          {
            if (slide_pos == 0)
            {
              show_scenario_example_ctl(slide_pos);
            }
            else if (slide_pos == 1)
            {
              show_scenario_example_ctl(slide_pos);
            }
            else if (slide_pos == 2)
            {
              show_scenario_example_ctl(slide_pos);
            }
            else if (slide_pos == 3)
            {
              show_scenario_example_ctl(slide_pos);
            }
            else if (slide_pos == 4)
            {
              show_scenario_example_ctl(slide_pos);
            }
          }
        }
        break;
      default:
        break;
    }
  }
  else if (KEY_SCAN() == 0 && test_flag == false)
  {
    delay(10);
    //    Serial.println("sleep_num +++  ....");
    sleep_num++;
    if (sleep_num == 6000)
    {
      EPD_Init();
      EPD_DeepSleep();

      sleep_num = 0;
      //Go to sleep now
      Serial.println("Going to sleep now ....");
      esp_deep_sleep_start();
    }
  }
}

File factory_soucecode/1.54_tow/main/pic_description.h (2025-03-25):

const unsigned char gImage_description[2888] = { /* 0X00,0X01,0X98,0X00,0X98,0X00, */
0XFF,0XFF,0XFF,0XFF,0XFF,0XFF,0XFF,0XFF,0XFF,0XFF,0XFF,0XFF,0XFF,0XFF,0XFF,0XFF,
0XFF,0XFF,0XFF,0XFF,0XFF,0XFF,0XFF,0XFF,0XFF,0XFF,0XFF,0XFF,0XFF,0XFF,0XFF,0XFF,
0XFF,0XFF,0XFF,0XFF,0XFF,0XFF,0XFF,0XFF,0XFF,0XFF,0XFF,0XFF,0XFF,0XFF,0XFF,0XFF,
0XFF,0XFF,0XFF,0XFF,0XFF,0XFF,0XFF,0XFF,0XFF,0XFF,0XFF,0XFF,0XFF,0XFF,0XFF,0XFF,
0XFF,0XFF,0XFF,0XFF,0XFF,0XFF,0XFF,0XFF,0XFF,0XFF,0XFF,0XFF,0XFF,0XCF,0XFF,0XFF,
0XFF,0XFF,0XFF,0XFF,0XFF,0XFF,0XFF,0XFF,0XFF,0XFF,0XFF,0XFF,0XFF,0XFF,0XFF,0XFF,
0X87,0XFF,0XFF,0XFF,0XFF,0XFF,0XFF,0XFF,0XFF,0XFF,0XFF,0XFF,0XFF,0XFF,0XFF,0XFF,
0XFF,0XFF,0XFF,0X03,0XFF,0XFF,0XFF,0XFF,0XFF,0XFF,0XFF,0XFF,0XFF,0XFF,0XFF,0XFF,
0XFF,0XFF,0XFF,0XFF,0XFF,0XFE,0X01,0XFF,0XFF,0XFF,0XFF,0XFF,0XFF,0XFF,0XFF,0XFF,
0XFF,0XFF,0XFF,0XFF,0XFF,0XFF,0XFF,0XFF,0XFC,0X00,0XFF,0XFF,0XFF,0XFF,0XFF,0XFF,
0XFF,0XFF,0XFF,0XFF,0XFF,0XFF,0XFF,0XFF,0XFF,0XFF,0XFF,0XF8,0X00,0X7F,0XFF,0XFF,
0XFF,0XFF,0XFF,0XFF,0XFF,0XFF,0XFF,0XFF,0XFF,0XFF,0XFF,0XFF,0XFF,0XFF,0XF0,0X00,
0X3F,0XFF,0XFF,0XFF,0XFF,0XFF,0XFF,0XFF,0XFF,0XFF,0XFF,0XFF,0XFF,0XFF,0XFF,0XFF,
0XFF,0XFE,0X01,0XFF,0XFF,0XFF,0XFF,0XFF,0XFF,0XFF,0XFF,0XFF,0XFF,0XFF,0XFF,0XFF,
0XFF,0XFF,0XFF,0XFF,0XFE,0X01,0XFF,0XFF,0XFF,0XFF,0XFF,0XFF,0XFF,0XFF,0XFF,0XFF,
0XFF,0XFF,0XFF,0XFF,0XFF,0XFF,0XFF,0XFE,0X31,0XFF,0XFF,0XFF,0XFF,0XFF,0XFF,0XFF,
0XFF,0XFF,0XFF,0XFF,0XFF,0XFF,0XFF,0XFF,0XFF,0XFF,0XFE,0X31,0XFF,0XFF,0XFF,0XFF,
0XFF,0XFF,0XFF,0XFF,0XFF,0XFF,0XFF,0XFF,0XFF,0XFF,0XFF,0XFF,0XFF,0XFE,0X31,0XFF,
0XFF,0XFF,0XFF,0XFF,0XFF,0XFF,0XFF,0XFF,0XFF,0XFF,0XFF,0XFF,0XFF,0XFF,0XFF,0XFF,
0XFF,0XFF,0XFF,0XFF,0XFF,0XFF,0XFF,0XFF,0XFF,0XFF,0XFF,0XFF,0XFF,0XFF,0XFF,0XFF,
0XFF,0XFF,0XFF,0XFF,0XFF,0XFF,0XFF,0XFF,0XFF,0XFF,0XFF,0XFF,0XFF,0XFF,0XFF,0XFF,
0XFF,0XFF,0XFF,0XFF,0XFF,0XFF,0XFF,0XFF,0XFF,0XFF,0XFF,0XFF,0XFF,0XFF,0XFF,0XFF,
0XFF,0XFF,0XFF,0XFF,0XFF,0XFF,0XFF,0XFF,0XFF,0XFF,0XFF,0XFF,0XFF,0XFF,0XFF,0XFF,
0XFF,0XFF,0XFF,0XFF,0XFF,0XFF,0XFF,0XFF,0XFF,0XFF,0XFF,0XFF,0X00,0X00,0X00,0X00,
0X00,0X00,0X00,0X00,0X00,0X00,0X00,0X00,0X00,0X00,0X00,0X00,0X00,0X00,0X00,0X00,
0X00,0X00,0X00,0X00,0X00,0X00,0X00,0X00,0X00,0X00,0X00,0X00,0X00,0X00,0X00,0X00,
0X00,0X00,0X00,0X00,0X00,0X00,0X00,0X00,0X00,0X00,0X00,0X00,0X00,0X00,0X00,0X00,
0X00,0X00,0X00,0X00,0X00,0X00,0X00,0X00,0X00,0X00,0X00,0X00,0X00,0X00,0X00,0X00,
0X00,0X00,0X00,0X00,0X00,0X00,0X00,0X00,0X00,0X00,0X00,0X00,0X00,0X00,0X00,0X00,
0X00,0X00,0X00,0X00,0X00,0X00,0X00,0X00,0X00,0X00,0X00,0X00,0X00,0X00,0X00,0X00,
0X00,0X00,0X00,0X00,0X00,0X00,0X00,0X00,0X00,0X00,0X00,0X00,0X00,0X00,0X00,0X00,
0X00,0X00,0X00,0X00,0X00,0X00,0X00,0X00,0X00,0X00,0X00,0X00,0X00,0X00,0X00,0X00,
0X00,0X00,0X00,0X00,0X00,0X00,0X00,0X00,0X00,0X00,0X00,0X00,0X00,0X00,0X00,0X00,
0X00,0X00,0X00,0X00,0X00,0X00,0X00,0X00,0X00,0X00,0X00,0X00,0X00,0X00,0X00,0X00,
0X00,0X00,0X00,0X00,0X00,0X00,0X00,0X00,0X00,0X00,0X00,0X00,0X00,0X00,0X00,0X00,
0X00,0X00,0X00,0X00,0X00,0X00,0X00,0X00,0X00,0X00,0X00,0X00,0X00,0X00,0X18,0X00,
0X06,0X00,0X00,0X00,0X00,0X00,0X00,0X00,0X01,0X80,0X00,0X00,0X00,0X00,0X00,0X00,
0X00,0X18,0X60,0X06,0X00,0X00,0X00,0X03,0XE0,0X18,0X00,0X01,0X80,0X00,0X03,0XE0,
0X00,0X00,0X00,0X00,0X00,0X60,0X00,0X00,0X00,0X00,0X07,0XE0,0X18,0X00,0X01,0X80,
0X00,0X07,0XE0,0X00,0X00,0X0E,0X87,0X18,0XF1,0XA6,0X51,0XC1,0XE3,0X86,0X60,0X3C,
0XE1,0X91,0XF0,0X71,0X46,0X60,0X00,0X00,0X0F,0X8F,0X98,0XF3,0XE6,0X73,0XE3,0XE7,
0XC6,0X60,0X3D,0XF1,0X91,0XF0,0XF9,0XC6,0X60,0X00,0X00,0X0D,0X8C,0XD8,0X63,0X66,
0X33,0X30,0X36,0X66,0X60,0X19,0X99,0X91,0X98,0XCC,0XC7,0XE0,0X00,0X00,0X0D,0X8C,
0XD8,0X63,0X66,0X30,0X31,0XE7,0XE6,0X60,0X18,0X19,0X91,0X98,0XCC,0XC3,0XE0,0X00,
0X00,0X0D,0X8C,0XD8,0X63,0X66,0X33,0X33,0X00,0X66,0X60,0X19,0X99,0XB1,0X98,0XCC,
0XC0,0X60,0X00,0X00,0X0D,0X8F,0X98,0XE3,0XE6,0X33,0XE3,0X77,0XC7,0XE0,0X39,0XF1,
0XF1,0XF0,0XF8,0XC0,0X60,0X00,0X00,0X0D,0X87,0X18,0XE1,0XE6,0X31,0XC1,0XE3,0X83,
0XE0,0X38,0XE1,0X71,0XF0,0X70,0XC0,0X60,0X00,0X00,0X00,0X00,0X00,0X00,0X60,0X00,
0X00,0X00,0X00,0X00,0X00,0X00,0X00,0X00,0X00,0X00,0X00,0X00,0X00,0X00,0X00,0X00,
0X00,0X60,0X00,0X00,0X00,0X00,0X00,0X00,0X00,0X00,0X00,0X00,0X00,0X00,0X00,0X00,
0X00,0X00,0X00,0X00,0X60,0X00,0X00,0X00,0X00,0X00,0X00,0X00,0X00,0X00,0X00,0X00,
0X00,0X00,0X00,0X00,0X00,0X00,0X00,0X00,0X00,0X00,0X00,0X00,0X00,0X00,0X00,0X00,
0X00,0X00,0X00,0X00,0X00,0X00,0X00,0X00,0X00,0X00,0X00,0X00,0X00,0X00,0X00,0X00,
0X00,0X00,0X00,0X00,0X00,0X00,0X00,0X00,0X00,0X00,0X00,0X00,0X00,0X00,0X00,0X00,
0X00,0X00,0X00,0X00,0X00,0X00,0X00,0X00,0X00,0X00,0X00,0X00,0X00,0X00,0X00,0X00,
0X00,0X00,0X00,0X00,0X00,0X00,0X00,0X00,0X00,0X00,0X00,0X00,0X00,0X00,0X00,0X00,
0X00,0X00,0X00,0X00,0X00,0X00,0X00,0X00,0X00,0X00,0X00,0X00,0X00,0X00,0X00,0X00,
0X00,0X00,0X00,0X00,0X00,0X00,0X00,0X00,0X00,0X00,0X00,0X00,0X00,0X00,0X00,0X00,
0X00,0X00,0X00,0X00,0X00,0X00,0X00,0X00,0X00,0X00,0X00,0X00,0X00,0X00,0X00,0X00,
0X00,0X00,0X00,0X00,0X00,0X00,0X00,0X00,0X00,0X00,0X00,0X00,0X00,0X00,0X00,0X00,
0X00,0X00,0X00,0X00,0X00,0X00,0X00,0X00,0X00,0X00,0X00,0X00,0X00,0X00,0X00,0X00,
0X00,0X00,0X00,0X00,0X00,0X00,0X00,0X00,0X00,0X00,0X00,0X00,0X00,0X00,0X00,0X00,
0X00,0X00,0X00,0X00,0X00,0X00,0X00,0X00,0X00,0X00,0X00,0X00,0X00,0X00,0X00,0X00,
0X00,0X40,0X00,0X21,0XE0,0X38,0XE1,0XF0,0XE3,0XE0,0X40,0X00,0X00,0X3E,0X00,0X00,
0X01,0XC0,0X00,0X00,0X40,0X00,0X02,0X20,0X24,0X91,0X11,0X10,0X20,0X40,0X00,0X00,
0X22,0X00,0X00,0X02,0X20,0X11,0X38,0X4F,0X0E,0X24,0X20,0X20,0X83,0X10,0X10,0X20,
0X47,0X0F,0X1C,0X62,0X48,0XB8,0XE6,0X20,0X12,0X24,0X49,0X12,0X24,0X20,0X20,0XE1,
0X10,0X71,0XE0,0X44,0X89,0X12,0X22,0X4D,0X24,0X20,0X20,0X0A,0X30,0X51,0X06,0X24,
0X20,0X10,0X80,0XF1,0X80,0X20,0X47,0X89,0X18,0X1E,0X2D,0X44,0X20,0X20,0X0E,0X2C,
0X51,0X18,0X24,0X20,0X09,0X00,0X11,0X00,0X20,0X40,0X89,0X16,0X02,0X35,0X44,0X26,
0X20,0X0C,0X24,0X59,0X12,0X22,0X20,0X0C,0X90,0X11,0X10,0X20,0X40,0X89,0X12,0X02,
0X33,0X24,0X22,0X20,0X04,0X3C,0X4F,0X1E,0X21,0XE0,0X7C,0XE0,0X10,0XE3,0XE0,0X47,
0X09,0X1E,0X02,0X32,0X38,0X21,0XC0,0X04,0X00,0X01,0X00,0X00,0X00,0X00,0X00,0X00,
0X00,0X00,0X00,0X00,0X00,0X00,0X00,0X00,0X00,0X00,0X02,0X00,0X01,0X00,0X00,0X00,
0X00,0X00,0X00,0X00,0X00,0X00,0X00,0X00,0X00,0X00,0X00,0X00,0X00,0X00,0X00,0X00,
0X00,0X00,0X00,0X00,0X00,0X00,0X00,0X00,0X00,0X00,0X00,0X00,0X00,0X00,0X00,0X00,
0X00,0X00,0X00,0X00,0X00,0X00,0X00,0X00,0X00,0X00,0X00,0X00,0X00,0X00,0X00,0X00,
0X00,0X00,0X00,0X00,0X00,0X00,0X00,0X00,0XE0,0XE0,0X0E,0X1C,0X3E,0X1C,0X7C,0X00,
0X02,0X10,0X00,0X00,0X00,0X00,0X00,0X00,0X00,0X00,0X00,0X91,0X10,0X09,0X12,0X22,
0X22,0X04,0X00,0X02,0X10,0X00,0X00,0X00,0X00,0X00,0X00,0X00,0X00,0X00,0X80,0X10,
0X08,0X10,0X62,0X02,0X04,0X0E,0X1E,0X38,0X0E,0X70,0X71,0X20,0X00,0X00,0X00,0X00,
0X00,0XE0,0X70,0X08,0X1C,0X22,0X0E,0X3C,0X09,0X12,0X10,0X12,0X48,0X91,0X20,0X00,
0X00,0X00,0X00,0X1C,0X81,0X81,0XC4,0X10,0X1E,0X30,0X04,0X0F,0X32,0X10,0X06,0X78,
0X31,0X20,0X00,0X00,0X00,0X00,0X01,0X01,0X00,0X02,0X20,0X02,0X20,0X04,0X01,0X32,
0X10,0X18,0X08,0XC1,0X20,0X00,0X00,0X00,0X00,0X00,0X91,0X10,0X03,0X12,0X02,0X22,
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
